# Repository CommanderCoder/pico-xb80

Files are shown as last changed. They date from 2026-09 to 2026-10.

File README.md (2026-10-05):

# pico-xb80

pico-xb80 is a small expansion-bus interface for 1970s and 1980s desktop machines, designed to allow a Raspberry Pi Pico 2 board to present an SD card-backed storage device to a Sharp MZ80K system.

https://youtu.be/xSwXQkPeJl4?si=bnu4Bi942s_XvJiR

Short Video of the pico-xb80 (http://www.youtube.com/watch?v=xSwXQkPeJl4?si=bnu4Bi942s_XvJiR "pico-xb80 on Sharp MZ80K")

## Supported hardware

Currently supported:

* [Sharp MZ80K](https://en.wikipedia.org/wiki/Sharp_MZ)

Possible future targets with additional effort:

* [Tandy TRS-80 and clones](https://en.wikipedia.org/wiki/List_of_TRS-80_clones)

## What it does

The project uses a Pico 2 board and an SD card to provide a file system to the Sharp MZ80K through the expansion bus. A small monitor ROM extension and host-side software allow the machine to access files stored on an SD card in a way that is compatible with the existing monitor and tape-handling model.

The software stack includes:

* SD card interface support for the Pico 2 board configuration used here, over hardware SPI where the wiring allows it and bit-banged 1-bit native SD mode otherwise
* `fatfs` by ChaN
* a custom expansion-bus implementation using the Pico PIO and DMA subsystems
* Sharp MZ80K-specific glue logic and ROM support for monitor commands such as `*FD`

## Hardware overview

Off-the-shelf components are used to keep the project accessible and inexpensive.

* Raspberry Pi Pico 2 / RP2350B mounted on an [Olimex Pico2-XXL](https://www.olimex.com/Products/RaspberryPi/PICO/PICO2-XXL/open-source-hardware)
* SD card socket mounted on the board
* Ribbon cable and jumper wires to connect the bus to the computer
  * Sharp MZ80K uses a [50-way ribbon cable](https://www.google.com/search?q=50+way+ribbon+cable)
  * [DuPont or similar jump wires](https://en.wikipedia.org/wiki/Jump_wire)

This is a prototype-style design intended to be simple to build and experiment with. A dedicated single-board version may be possible in the future, but the current approach uses the Olimex board for flexibility.

## Development environment

The project is built and developed with:

* VS Code
* Raspberry Pi Pico SDK
* Git - [git in VSCode](https://code.visualstudio.com/docs/sourcecontrol/overview) 
* Python 3

### Z80 code tooling

> Important: you will need to build your own copy of `sjasmplus` for your platform.

The repository includes support for:

* [sjasmplus](https://github.com/z00m128/sjasmplus) for assembling Z80 code into machine-code binaries
* `bin2header.py` to convert binary output into a C header suitable for inclusion in the Pico firmware

## Utility tools

The project includes a small set of helper scripts for working with Sharp MZ80K file images:

* `filehandle_path.py` — scans a Sharp MZ80K binary for tape-handler calls and rewrites them to use the SD-backed handlers
* `mz_tape_info.py` — inspects file images and reports the file type plus whether they have already been patched

# Build and upload

## Wiring

Only the right-hand column of pins is used from EXT1 and EXT2 on the Olimex board.

<div style="display: flex; gap: 1rem;">
  <div style="flex: 1;">

| Olimex EXT1 | MZ80K | XB Signal |
|---|---|---|
| P1 | nc | |
| P3 | A25 (mark) | D0 |
| P5 | A24 | D1 |
| P7 | A23 | D2 |
| P9 | A22 | D3 |
| P11 | A21 | D4 |
| P13 | A20  | D5 |
| P15 | A19 | D6 |
| P17 | A18 | D7 |
| P19 | nc | |
| P21 | nc | |
| P23 | nc | |
| P25 | nc | |
| P27 | nc | |
| P29 | nc | |
| P31 | B10 | NWR |
| P33 | B8 | NRD |
| P35 | B6 | NIOREQ |
| P37 | B4 | NMREQ |
| P39 | B3 | GND |

  </div>

  <div style="flex: 1;">

| Olimex EXT2 | MZ80K | Signal |
|---|---|---|
| P1 | nc | |
| P3 | A16 | A0 |
| P5 | A15 | A1 |
| P7 | A14 | A2 |
| P9 | A13 | A3 |
| P11 | A12 | A4 |
| P13 | A11 | A5 |
| P15 | A10 | A6 |
| P17 | A9 | A7 |
| P19 | nc | |
| P21 | nc | |
| P23 | A8 | A8 |
| P25 | A7 | A9 |
| P27 | A6 | A10 |
| P29 | A5 | A11 |
| P31 | A4 | A12 |
| P33 | A3 | A13 |
| P35 | A2 | A14 |
| P37 | A1 | A15 |
| P39 | nc | |

  </div>
</div>

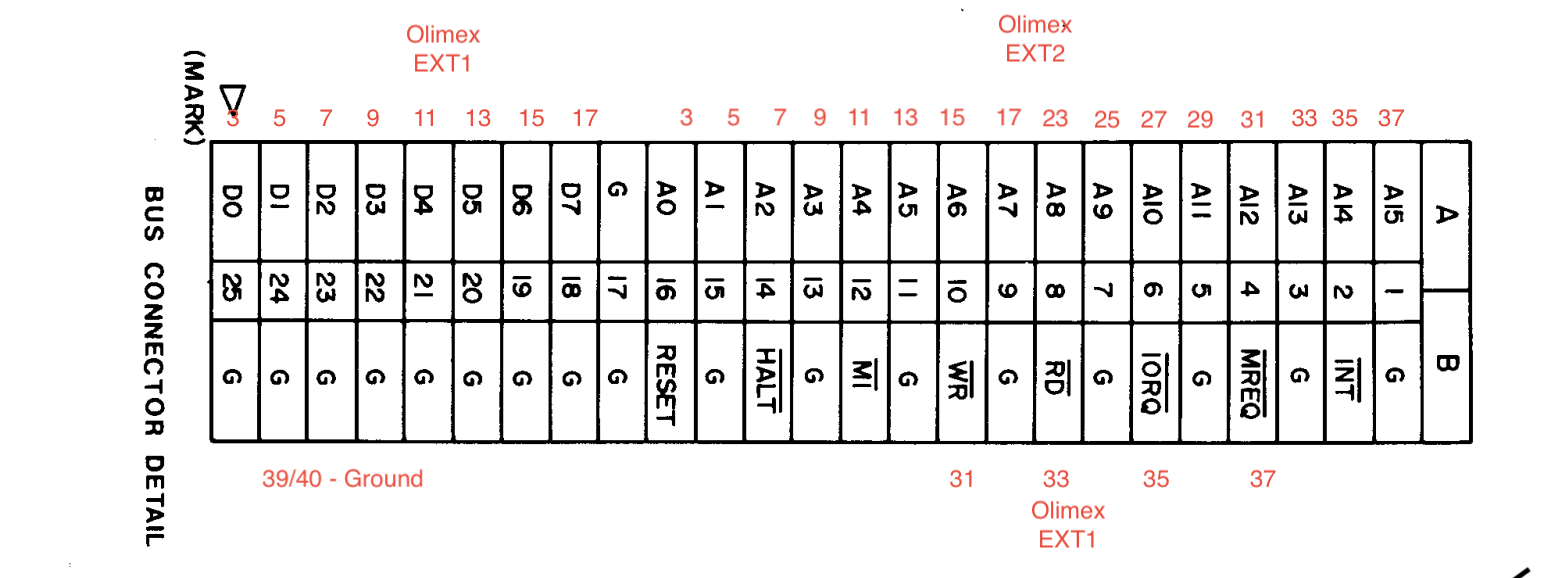
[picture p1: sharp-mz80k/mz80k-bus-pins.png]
sharp-mz80k-bus-pins


## Building

From the project root:

```bash
cmake -S . -B build -G Ninja
cmake --build build
```

## Uploading

To put the Pico into bootloader mode:

* hold the BOOT button
* connect the board to your computer via USB

Then upload the firmware using VS Code with the Pico extension, or use the project task configuration already provided in the workspace.

## SD card layout

Create an SD card with a root-level folder named `MZ_FD`. Place the files you want to access inside that directory and give them the `.MZF` extension. The file `0000.MZF` is loaded whenever `*FD` is used from the monitor.

## Patch workflow

Because the monitor ROM cannot be modified in software, a replacement ROM or a patched program image is required to redirect tape-file operations to the SD-backed handlers.

The helper scripts make this easier:

* `mz_tape_info.py` identifies files that use tape-file logic
* `filehandle_path.py` patches those files to call the SD-handler routines instead

## Power

The board can be powered either from the host laptop USB port or from a standard USB power supply.

# Operating instructions

See [OPERATING.md](OPERATING.md) for instructions on using the interface from the Sharp monitor ROM.

# Reference and acknowledgements

Thanks to:

* [MZ80K_SD](https://github.com/yanataka60/MZ80K_SD)
* [Atom-DVI](https://github.com/cmoulang/Atom-DVI)
* [MZ-80A](https://mz-80a.com/)
* [MZ-Archive](https://mz-archive.co.uk/)
* [Sharp MZ](https://www.sharpmz.net/)
* the wider retro-computing community for technical discussion and reference material

This project also benefited from discussions and examples from several AI systems used during development, but the project itself is intended to stand on its own technical merits.

# Technical notes

## The software:
* SD Card interface software (initially from prompts to Claude.ai).  The Olimex Pico2-XXL has two variants.  One use 1-bit communication protocol and the other uses the 4-bit protocol.  My board used 1-bit so the software was originally built for this.

  `SdCard::detect_board_revision()` works out which board it is running on first, since the two Olimex revisions wire the card differently.  Revision A puts SD_DAT0 on GPIO12 and leaves R24 - the link between GPIO9 and the card's CS pin - unpopulated, so it can only be bit-banged.  Revision B moved SD_DAT0 to GPIO24 (GPIO12 collides with the RP2350's HSTX/HDMI block) and ships wired for SPI.  The check is electrical, not a conversation with the card: it looks for the 10k pull-up the SD_DAT0 net carries on the board, so it needs no card in the socket and sends no commands - which matters, because a `CMD0` seen with CS low latches a card into SPI mode until it is next powered down.

  That gives two transports, picked at startup by `SdCard::initialize()`:
  * **SPI** - used on Revision B.  The card is driven by one of the RP2350 SPI blocks, so a sector moves as 512 hardware-clocked bytes at 12.5MHz rather than 4096 bit-banged GPIO transitions.  This needs CS on a GPIO and CLK/DI/DO on pins that can carry the SCK/TX/RX functions of a single SPI instance - GPIO9/10/11/24 are all `spi1`, so they qualify.
  * **1-bit native SD** - used on Revision A, and the fallback everywhere else: whenever the wiring cannot carry SPI or the card does not answer the SPI probe.  CMD/CLK/DAT0 are bit-banged at roughly 500kHz with the CPU busy-waiting for the whole sector.

  If the detected wiring fails to initialise, the other revision's wiring is tried before giving up.

* Expansion Bus - provides a shared memory on the address bus.  [Pico PIOs](https://www.raspberrypi.com/news/what-is-pio/) rapidly reads addresses and data which several DMAs pump in and out of 64Kx16bit words (128Kb).
  * heavily influenced by [ATOM-DVI](https://github.com/cmoulang/Atom-DVI) after speaking with Chris about his project at an ABUG event. 
* pico-xb80_mz80k - the specific Sharp MZ80K interface.  
  * Z80 *ROM* this is shared on the bus at `0xF000` so that the Monitor ROM can jump to it with an `*FD` command.
  * Mailbox addresses so that the Z80 can send and receive commands and data to/from the Pico
  * Communcation with the SD card via the SD Card interface and `fatfs`

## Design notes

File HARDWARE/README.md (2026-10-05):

# Hardware

## Revision 1 schematic

The [`xb80_universal.pdf`](xb80_universal.pdf) file contains the first hardware revision schamatic design for the board.

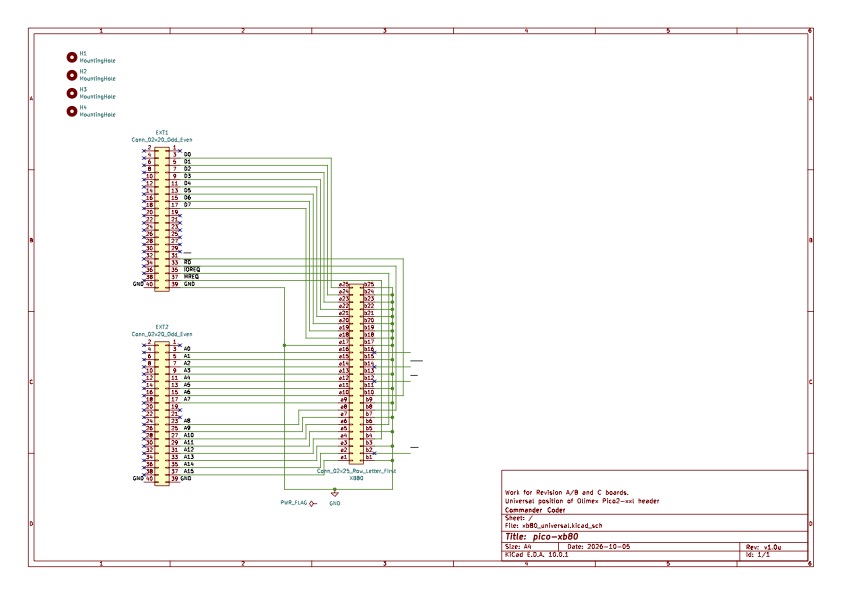
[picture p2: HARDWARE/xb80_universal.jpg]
PCB


## Revision 1 visual reference

Render of the assembled first-revision board layout and component placement for quick visual reference.

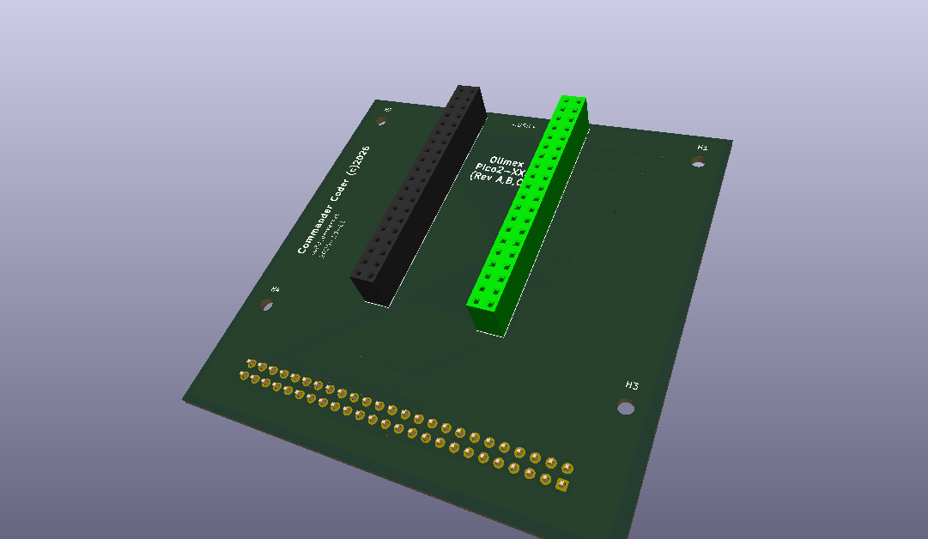
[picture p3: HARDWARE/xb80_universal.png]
SCHEMATIC


Pico on top with headers underneath.  Ribbon cable underneath that.

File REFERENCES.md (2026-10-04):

# References

 - [Olimex Pico2-XXL](https://www.olimex.com/Products/RaspberryPi/PICO/PICO2-XXL/open-source-hardware)
 - [Commented Assembly Listing for SP-5025 Monitor](https://mz-80a.com/Files/Manuals/Monitor-Disassembly-80K.pdf)
 - [Sharp MZ Manuals](https://www.sharpmz.net/mz-80k/dldsh80k.htm)
 - [MZ80K Service Manual](https://www.sharpmz.net/mz-80k/download/sm80k.pdf)
 - [Z80 CPU Manual](https://www.zilog.com/docs/z80/um0080.pdf)
 - `sjasmplus`
   - [Documentation](https://z00m128.github.io/sjasmplus/documentation.html)
   - [Installation](https://github.com/z00m128/sjasmplus/blob/master/INSTALL.md)
 - [Yanataka MZ80K-SD](https://github.com/yanataka60/MZ80K_SD)
 - [CMoulang Atom-DVI](https://github.com/cmoulang/Atom-DVI)

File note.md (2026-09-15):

I wanted to be able to load programs quickly onto my Sharp MZ80K.  Quicker than the super speedy in-built tape deck.

I hunted around and found this:
https://github.com/yanataka60/MZ80K_SD

After looking at the design I thought I might be able to use a different microprocessor
than an arduino.  An Arduino Mega maybe?  

I'd spoken with someone recently about bus sniffing with a Pico2B (RP2350B).  The 'B' model has 48 GPIO pins so that can connect to all 16 address lines, 8 data lines and 4 control lines on the MZ80K expansion bus.

So that's what I did.  I bought an Olimex Pico2-XXL https://github.com/OLIMEX/RP2350-PICO2-XXL/tree/main (it has the 48 GPIO's exposed) and it has an Micro-SD card slot.

After a couple of months of tinkering I got the Olimex to sniff read/writes on the bus so that it could intercept memory writes and reads.  This means it could respond to reads and writes between 0F000H and 0FFFFH. (I've made it possible to make individual address inactive, read-only, write-only and read-write)

The Olimex Pico2-XXL has two varients.  One with 1-bit MMC access and the other with 4-bit access.  Mine has 1 bit mmc which doesn't have that much example code.  CoPilot helped here, with some support from Claude.AI, and my own tinkering.

So now I have an SD card containing Z80 programs, SP-5025 Basic and Basic programs.  The Pico has a version of the ROM from Yanataka's site embedded into it and now I can use *FD to load binary programs, and a patched version of SP-5025 Basic to load Basic programs.

No other hardware is needed apart from ribbon cables and a USB power supply.

NOTE: The RP2350 nominally operates at 3.3v but the internet suggests it is 5v tolerant with some caveats. (A4 version of the chip is definitely tolerant but A2, which is the same as mine, requires 5V on IOVCC pin before drive the other pins.)

--

If you're interested in this, then get in touch.  I don't plan to release any code until I've tidied it up a lot.

I don't have an MZ700 so I cannot test it.

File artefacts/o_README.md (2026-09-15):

# PICO tools to upload the 

cmake -S . -B build -G Ninja

# ARDUINO-CLI tool to upload to arduino

# List all available boards
arduino-cli board listall | grep -i mega

# Detect connected boards
arduino-cli board list

cd arduino_eb_test
arduino-cli compile --fqbn arduino:avr:mega arduino_eb_test.ino

arduino-cli upload -p /dev/cu.usbserial-0001 --fqbn arduino:avr:mega arduino_eb_test.ino

# build arduino mega - mimics the Z80 cpu
ARDUINO_PORT=/dev/cu.usbserial-0001
arduino-cli compile --upload -p "$ARDUINO_PORT" --fqbn arduino:avr:mega arduino_eb_test.ino && arduino-cli monitor -c 115200 -b arduino:avr:mega -p "$ARDUINO_PORT"

# to view the output

# from pico
minicom -b 115200 -D /dev/tty.usbmodem1101

# from arduino
minicom -b 115200 -D /dev/cu.usbserial-0001

or

arduino-cli monitor -p /dev/cu.usbserial-0001 -c 115200 -b arduino:avr:mega

# build Z80

./sjasmplus test.s --lst && hexdump -v -e '8/1 "0x%02x, " "\n"' test.bin > rom1.h 

https://mz-80a.com/Files/Manuals/Monitor-Disassembly-80K.pdf

	; just show a message...
	    LD   DE, MSG_LD1
        CALL MSGPR
        CALL NEWLIN
        LD   DE, MSG_LD2
        CALL MSGPR
		CALL LETLN
        JP   MON  ; Jump back to Monitor instead of RET

CURSORHOME		EQU		16H ; clear screen

MSG_LD1: DB   CURSORHOME, 'HELLO ANDREW AND KAREN', 0DH
MSG_LD2: DB   'THIS PROGRAM IS SITTING INSIDE MY LITTLE BOX', 0DH

# MZ80K Memory Map

RAM - 48K runs from 0x1000-0xCFFF (0xC000 bytes or 49152)
Workspace RAM for Monitor - 0x1000-0x11FF
RAM for programs 0x1200-0xcfff

## Basic
0x1200-0x4806

## Monitor
0x0000-0x0fff

## Video
0xD000-0xD3FF
Only 1000 locations seen. The other 24 are never shown
The locations are repeated 4 times, so making the 4096 addresses up to DFFF

MZ80A has 2k of video ram but each 1k selected in a special way.

## Memory Expansion & Addressing

## I/O At $E000 Locations

E000 keyboard driver
E001 keyboard receiver
E002 read-curser timer, cassette sense
E003 motor pulse, led

*8522 PIA*
E000 BEING PORT A
E001 BEING PORT B
E002 BEING PORT C
E003 BEING THE CONTROL WORD

all the peripherals ; 

*8253 TIMER*
E007 CONTROL WORD.
E006 COUNTER 2
E005 COUNTER 1
E004 COUNTER 0

*555 TEMPO TIMER*
E008 timer

### MZ80A EXTRAS
E00C MEMORY MONITOR EXCHANGE
E010  MEMORY MONITOR NORMAL
E014 STADNARD SCREEN DISPLAY
E015 REVERSE SCREEN DISPLAY
E200-E2FF DISPLAY RAM

_Maybe use 0xE300 for moving data to and from the PICO, But F000-FFFF is reserved and available_

MZ80A - has user ram/rom slot addressed at E800-EFFF - if E800 is NULL then this rom will run on powerup
..
plenty more

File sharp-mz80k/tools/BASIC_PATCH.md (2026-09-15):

# PATCHING BASIC

Load and Save routines exist within the MONITOR rom.  Cannot patch the Monitor ROM (hardware) using software
so any program which loads or saves will need to be patched.  

This can be done by searching through the machine code looking for jumps to the load or save routines.

These routines are in the monitor ROM at these location, and have these hex codes to jump.
 ADDR MC     LABEL: pseudo-assembler
 0021 C33604 PHEAD: JP Phead Punch header.
 0024 C37504 PDATA: JP Pdata Punch data.
 0027 C3D804 LHEAD: JP Lhead Load header.
 002A C3F804 LDATA: JP Ldat a Load data.
 OO2D C38805 CHECK: JP Check Checks file.

0xC3 is the JP instruction, and PHEAD code is at location 0x0436 in the monitor rom, for example.

Normal Sharp assembler programs will jump to 0x0021 (for example) and this will jump to 0x0436 which performs the 'write' header. (Punch was used for Write back in the 1970's on this machine).

## Without changing the rom

The replacement jump functions are in the FD rom at these locations:

 F004 C3 E7 F7     ENT1: 	JP		MSHED ; PHEAD (punch header)
 F007 C3 32 F8     ENT2: 	JP		MSDAT ; PDATA (punch data)
 F00A C3 66 F8     ENT3: 	JP		MLHED ; LHEAD (load header)
 F00D C3 50 F9     ENT4: 	JP		MLDAT ; LDATA (load data)
 F010 C3 83 F9     ENT5: 	JP		MVRFY ; CHECK (Checks file)

Need to patch every program. The first of these is naturally BASIC.  To patch BASIC need to look for 

 CALL 0021H
 and replace with
 CALL F004H

 CALL 0027H
 and replace with
 CALL F00AH

 so simply search through the BASIC binary and replace
 0xcd, 0x21, 0x00 _with_ 0xcd, 0x04, 0xf0
 0xcd, 0x24, 0x00 _with_ 0xcd, 0x07, 0xf0
 0xcd, 0x27, 0x00 _with_ 0xcd, 0x0a, 0xf0
 0xcd, 0x2A, 0x00 _with_ 0xcd, 0x0d, 0xf0
 0xcd, 0x2D, 0x00 _with_ 0xcd, 0x10, 0xf0

# Monitor ROM patch for FD_rom1.s

If you feel patching the ROM would be best, thus works for ALL existing Sharp programs then 
you replace the code at these locations to jump to the routines in the FD rom.

　0437 : D5 → C3
　0438 : C5 → 04
　0439 : E5 → F0
== JP F004

　0476 : D5 → C3
　0477 : C5 → 07
　0478 : E5 → F0
== JP F007

　04D9 : D5 → C3
　04DA : C5 → 0A
　04DB : E5 → F0
== JP F00A

　04F9 : D5 → C3
　04FA : C5 → 0D
　04FB : E5 → F0
== JP F00D

　0589 : D5 → C3
　058A : C5 → 10
　058B : E5 → F0
== JP F010

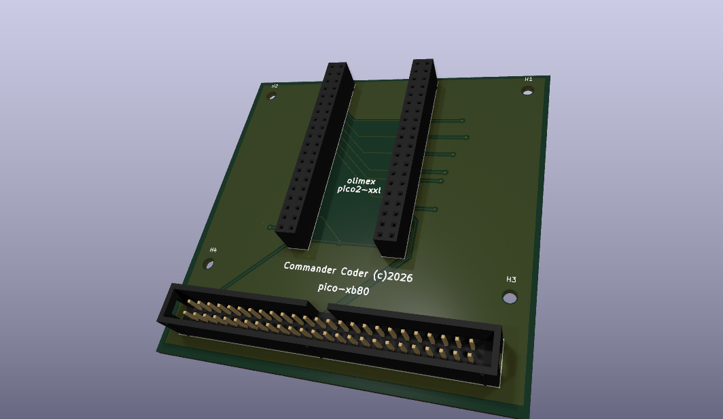
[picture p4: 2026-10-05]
HARDWARE/xb80_1/xb80_1.png

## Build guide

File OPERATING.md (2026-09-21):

# Operator Guide

## Preparing SD Card

All files must be within a subfolder called /MZ_FD and they must be binary files (no zips *yet*) and they must have the extension `.mzf` (case insensitive)

## `*FD`

Boot the file named 0000.mzf on the SD card use.  This is a convenience to startup any application quickly on the machine. A copy of BASIC is usually a good choice for this file.

## `*FDF`

Boot a File Menu which lists all files on the SD card.

# File Menu

## Help

> H

Display a help page explaining these navigation keys using 1 or 2 word phrases.

## Navigation

> W S

Use W/S to move up and down the list.

> , .

Use `,` and `.` to turn pages backward and forward (if there are multiple pages of files).

> X or ENTER

Load and execute (run) the file

> L

Load the file but do not execute it.  The load address is reported and you are returned to the monitor, so the loaded program can be started with `G` when you are ready.

> F

Filter the list by the next letter that you type. e.g. `F  B` would list only files beginning with B.

Press ENTER or SHIFT+BREAK at the `FILTER LETTER?` prompt to clear the filter and show every file again.

> T

Toggle between showing Basic, Machine code and other file types.  Each press cycles `ALL` → `BASIC` → `M-CODE` → `OTHER` → `ALL`, and the current setting is shown on the status line at the top of the screen.

A file counts as machine code when its MZF header type byte is 01H, as Basic when it is 02H, and as other for any other value.

> A

Copy the file to `0000.mzf`.  This enables changing the autoboot file from within the file menu.

> C 

Copy this file.  You will be prompted for a new filename.  If the new filename is the same as another [IBF filename](#ibf-filename) then the operation will fail.

The new name is applied to both the [IBF filename](#ibf-filename) and the SDCard filename of the copy, so the copy does not inherit the original's name.

> R

Rename this file.  You will be prompted for a new filename.  If the new filename is the same as another [IBF filename](#ibf-filename) then the operation will fail.

The new name is applied to both the [IBF filename](#ibf-filename) and the SDCard filename, exactly as it is when saving.  This is the way to give a file a name of its own when it shares one with another file.

> D

Delete this file. You will be prompted to confirm.

> P

Printout (Dump to screen) the contents of the file as 128 bytes per screen.

Once one screen is displayed, it will show "NEXT:ANY BACK:B BREAK:SHIFT+BREAK" and wait for instructions. Press B to display the previous 128 bytes, SHIFT+BREAK to cancel, and any other key to display the next 128 bytes.

If the file size is not divisible by 128 bytes, the last page will be filled with 00H until it reaches 128 bytes.

> SHIFT+BREAK

Exit back to the monitor.

## Filenames

Filenames on cassette are limited to 16 characters (plus a terminator character).

Filenames on the SD card have a much larger limit, but when listing filenames and referencing files from programs like BASIC, the [IBF filename](#ibf-filename) is used from with in the file header.

### IBF filename

Because files on tape or punch cards came sequentially, the filename is stored within the header of the file and not in a file table like they are on hard drives.  This filename is called the IBF by Yanataka.

The File Menu lists IBF filenames, and every command that takes a filename matches on the IBF filename first, falling back to the SDCard filename if nothing matches.  That fallback is what lets `*FD` find `0000.mzf`, whose IBF filename is whatever program it happens to hold.

### Duplicate IBF filenames

Nothing stops two files having the same IBF filename, and it happens easily: a patched copy of a program usually keeps the header of the original it was made from.

Where several files share an IBF filename, the listing tags each one `<1`, `<2`, `<3` and so on, in the order they are found on the card:

```
BASIC SP-5025<1
BASIC SP-5025<2
```

The tag is added to the end of the name, or replaces the last few characters when the name is already too long to grow.

In the File Menu the tags are only there so you can tell the rows apart: every operation (`X`, `L`, `A`, `C`, `R`, `D`, `P`) acts on the highlighted row itself, never on its name, so it always affects exactly the file you are pointing at.

> The tags exist only in the listing.  **The files on the card are not altered** and their headers still hold the original name, so a tag can move if you add or remove files.  Use `R` to give a file a name of its own if you want one that will not change.

Where a file must be named — from BASIC or the command line — the tagged name picks out one particular file, and an untagged name finds the first file carrying it.

## Loading from BASIC and other programs patched for `Pico-XB80`

BASIC and other programs will call routines within the monitor to load and save (*punch*) files.  These would take the file in memory and save it to cassette (or punch card!) starting at a known address, for a known length, and with a known execution address when it is loaded again.

> ⚠️ SAVE filenames must have fewer than 17 characters.

Just like with Cassette (CMT), please enter the file name and other information according to the input method and rules specified by the application and save it.

When saving, the entered filename will be applied to both the [IBF filename](#ibf-filename) and the SDCard filename.

The `.mzf` extension is automatically added to the SDCard filename.

For example, in BASIC SP-5030...

`SAVE "TEST"`

Will create a BASIC file called TEST.mzf with the IBF filename `TEST`.

> ⚠️ LOAD filenames must have fewer than 17 characters.

Although you can specify an IBF file name after commands such as L and LOAD specified by the application, simply press the ENTER key after the command such as L or LOAD without specifying an IBF filename will display the File Menu.

# Additional Command Line (after Yanataka MZ80K-SD)

## FD

The following commands are available from the MONITOR command input.  That is the `*` prompt.  All filenames are their [IBF filename](#ibf-filename) not the filename on the SDCard.

> FDS saddr eaddr xaddr filename

This command saves the data from the save start address to the save end address using the given filename.  The filename must have fewer than 17 characters and it will be the IBF filename, and the SDCard filename suffixed with `.mzf`

The save start address, save end address, and execution start address are specified using 4-digit hexadecimal numbers.

`*FDS　1200　2FFF　1200　TEST`

> FDM saddr

This displays the memory contents of the MZ-80K, starting from the address, in 128-byte segments per screen.

Once one screen is displayed, it will show "NEXT:ANY BACK:B BREAK:SHIFT+BREAK" and wait for instructions. Press B to display the previous 128 bytes, SHIFT+BREAK to cancel, and any other key to display the next 128 bytes.

You can cancel the display at any time by pressing SHIFT+BREAK, even while a single screen is being displayed.

> FDW saddr hexbytes* [CR]

The hexbyte (multiple 2-digit hexadecimal values), starting from the address, is written to the MZ-80K's memory.

Enter the data to be written as two hexadecimal digits after the starting address, and then press the ENTER key. Spaces separating the data will be ignored, so they can be included or omitted.

You can have any number of byte data entries in a 2-digit hexadecimal format, as long as they fit on a single line.

Enter a line of data and press the ENTER key to write it into memory. The next address will then be displayed, allowing you to continue entering data.

Furthermore, by correcting the address, it is possible to go back and make corrections or write data to a different address.

To stop writing data, press the ENTER key without writing any data to the displayed address.

If you enter a number other than hexadecimal and press the ENTER key, the system will write the valid data up to the point immediately before the non-hexadecimal input and display the next address.

`*FDW　1200　01　02　03　04　05　06　07　08`

`*FDW　1200　0102030405060708`

`*FDW 1200` (when stopping)

`*FDW 1200 12 34 5/` (Written up to 12 34)

# MZ700

    There is no support for MZ700 yet.

Note that while the MZ-700's floppy disk drive startup command is actually just the letter 'F', we've standardized the operation method to use 'FD'.

FDZ[CR]
　[For MZ-700 only] This program functions the same as "FT.MZT," which was created for the MZ-700. After copying MONITOR 1Z-009A or 1Z-009B to the back RAM and applying the patch, the MONITOR on the back RAM will start.

　If executed on an MZ-80K, it will result in a RESET operation.

FDU[CR]
　[For MZ-700 only, only when resetting while operating with the rear RAM MONITOR] Switches to rear RAM and starts the rear RAM MONITOR.

　Note: Running this program without the MONITOR module in the background RAM will cause it to malfunction.

　If executed on an MZ-80K, it will result in a RESET operation.

# S-OS SWORD

    This is untested.

When using [S-OS SWORD](https://handwiki.org/wiki/Software%3AS-OS), immediately after startup, set the device to "DV S:" and configure each device as a SYSTEM device.

This might only be the case with FUZZY BASIC, but when using a common format device, I couldn't omit the IBF file name with the LOAD command.

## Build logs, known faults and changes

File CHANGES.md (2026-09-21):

# Changes

Bringing `sharp-mz80k/FD_rom.s` into line with `OPERATING.md`.

`OPERATING.md` was treated as the specification throughout. Where the ROM and the
document disagreed, the ROM was changed; the document was only edited where it
contradicted itself or left behaviour undefined.

## Summary

Before this pass the ROM implemented roughly a quarter of what the operator guide
described. There was no monitor command-line parser at all — `*FD` went straight to
the file menu — and the menu supported six keys out of the thirteen documented. Four
of the Pico-side handlers that the documented menu operations depend on were
addressing the wrong directory and could never have succeeded.

Every monitor command and menu key documented in `OPERATING.md` is now implemented. The
ROM grew from 1342 to 3181 bytes, leaving 908 bytes of the 4089-byte budget free.

One documented behaviour is still missing: the guide says that pressing ENTER after
`LOAD` without naming a file should bring up the File Menu. `MLHED` still reports
`NO FILENAME` instead. Entering the menu from inside BASIC means never returning to it,
so this needs a decision about what should happen afterwards rather than a quick patch.

---

## Decision that needed a call

`OPERATING.md` assigned `A` and `D` to two different things each: page-back and
page-forward under "Navigation", and "copy to 0000.mzf" (`A`) and "delete" (`D`) in
the per-key list below it. Both could not be true.

Resolved in favour of the per-key list, because it is the more detailed and more
recently written of the two. Paging moved to `,` and `.`, and the Navigation section
of `OPERATING.md` was updated to match.

---

## `sharp-mz80k/FD_rom.s`

### Monitor command line — all of this was missing

The ROM had no parser. It jumped straight to the file menu from `0xF001`, so none of
the documented commands worked and `*FD` did the wrong thing.

Added `FDSTART`, which reads the command line out of `LBUF` (tolerating a missing
`*` prompt character) and dispatches:

| Command | Behaviour |
| --- | --- |
| `*FD` | Loads and runs `0000.mzf` (SD command `0x81`) |
| `*FDF` | Opens the file menu |
| `*FDS saddr eaddr xaddr name` | Saves a memory block (SD command `0x80`) |
| `*FDM saddr` | Displays memory, 128 bytes per screen — no Pico traffic |
| `*FDW saddr hexbytes` | Writes hex byte pairs into memory, then re-prompts |

`*FDS` validates that the end address is above the start address and that a filename
is present, reporting `ADDRESS FAILED!` / `FILENAME FAILED!` as the guide describes.

`*FDM` honours the documented "cancel at any time with SHIFT+BREAK, even while a
single screen is being displayed" by testing the key between every byte printed, not
just at the page prompt.

`*FDW` re-prints `*FDW nnnn ` after each line so the monitor's line editor picks the
whole line back up, stops on an empty line, and writes the valid data up to the first
non-hex character — all as documented.

### File menu keys

Previously only `W`, `S`, `A`, `D`, `R`, `/` and BREAK did anything. Now:

| Key | Action | Status |
| --- | --- | --- |
| `W` / `S` | Up / down one line | was present |
| `,` / `.` | Page back / forward | replaces `A`/`D` |
| `X` or ENTER | Load and run | `X` added |
| `L` | Load without running | added |
| `H` | Help page | added |
| `F` | Filter by next letter typed | replaces the old `/` line-input search |
| `T` | Cycle ALL → BASIC → M-CODE → OTHER | added |
| `A` | Copy to `0000.mzf` (SD `0x82`) | added |
| `C` | Copy file (SD `0x87`) | added |
| `R` | Rename file (SD `0x85`) | added, was "run" |
| `D` | Delete file (SD `0x84`) | added, was "next page" |
| `P` | Print/dump file (SD `0x86`) | added |
| SHIFT+BREAK | Exit to monitor | was present |

`L` reports the load address and returns to the monitor rather than to the menu,
since a loaded program may sit on top of the menu's own work area at `0xC800`.

A status line now shows the active type filter and letter filter.

### Key code handling — corrected

The monitor's `GETKY` at `001BH` returns *device* codes, not plain ASCII: CR is `66H`
and SHIFT+BREAK is `64H` (confirmed against the SP-1002 subprogram documentation).
Both alias onto lower-case letters once bit 5 is cleared — `64H & 5FH` is `'D'` and
`66H & 5FH` is `'F'`.

The older `artefacts/FD_rom_v0.1.s` masks with `AND 5FH` *before* testing for BREAK,
which means BREAK reads as `D` and CR reads as `F`. That idiom was deliberately **not**
carried over. The new dispatcher tests `64H` and `66H` first and never masks, which is
what makes it safe to bind `D` (delete) and `F` (filter) at all.

### Paging with a filter active — fixed

`GET_PAGE` used to start at raw index `page × 16` and scan exactly 16 entries, keeping
whichever matched. With a filter on, that produced short pages and silently skipped
files. It now counts *matching* entries: it skips `page × 16` matches, then collects up
to 16 more.

### Repeated directory rescans — fixed

`LOAD_SELECTED` called `GET_FILE_COUNT` on every iteration of its file-scanning loop,
and each of those triggers a full directory scan on the Pico. The scan is gone
entirely: `GET_PAGE` now records each row's Pico file index in a new `INDEX_BUFFER`,
so the selected file is looked up directly.

### Other fixes in the ROM

- `CLEAR_SCREEN` used to reset `CURSOR_POS`, so every redraw jerked the highlight back
  to the top of the page. It now only clears the screen.
- `DRAW_SCREEN` clamps `CURSOR_POS` to the last populated row, so changing a filter
  cannot leave the marker pointing past the end of a now-shorter page.
- `MOVE_DOWN` returned the cursor unchanged on an empty page and could step past the
  end if `CURSOR_POS` was already out of range; both are now guarded.
- Filenames are sent with the new `SNDNAME`, which emits the name, its CR, then NUL
  padding to exactly 33 bytes. The Pico needs the CR for `addmzf()` and the NUL for
  `addrootdir()`; the old code sent whatever happened to follow the name in memory.
- `*FDW`'s re-prompt loop now detects a BREAK out of `GETL` (reported as `1BH` in the
  first column) instead of re-parsing a line that is not there and looping forever.
- Dropped the unused `STCMD` wrapper and the write-only `FILE_COUNT` variable.
- `ENT1`–`ENT5` remain at `0xF004`, `0xF007`, `0xF00A`, `0xF00D` and `0xF010` —
  verified against the addresses `sharp-mz80k/tools/filehandle_patch.py` patches in.

---

## `sharp-mz80k/sharp_mz.cpp`

### Wrong directory on four handlers — fixed

`f_del()`, `f_ren()`, `f_dump()` and `f_copy()` called `addmzf()` but never
`addrootdir()`, unlike `f_save()`, `astart()` and `mon_whead()` which call both.

`ffconf.h` sets `FF_FS_RPATH 2` and nothing in the project ever calls `f_chdir()`, so a
bare `TEST.mzf` resolves to `/TEST.mzf` — not `/MZ_FD/TEST.mzf`. Every delete, rename,
dump and copy would therefore have reported "file not found". Since `OPERATING.md`
documents all four as working menu operations, they had to be fixed for the new ROM
keys to do anything.

Added a `recv_path()` helper that receives the name and builds the full path. It also
guarantees the CR and NUL terminators that `addmzf()` and `addrootdir()` each rely on,
which the raw 33-byte read did not.

### `FILEINFO` (`0xA1`) now reports the file type

The `T` key needs to know whether each file is BASIC or machine code, and the listing
protocol carried only the name. `sendFileName()` now sends the MZF header type byte
(header offset 0) immediately after the status byte and before the name.

`getFileAttribute()` reads that byte by opening the file at the given index. It is read
per listed entry rather than cached during `establishFileList()`, which would have
added an open for all 255 possible files to every directory scan.

**This is a protocol change.** The ROM and the Pico firmware must be updated together —
an old ROM against this firmware will read the type byte as the first character of the
filename.

### Off-by-one in ROM upload

`SharpMZ_initialise()` copied the ROM with `i <= fd_rom_start + fd_rom_size`, reading
one byte past the end of `fd_rom_data[]`. Changed to `<`.

---

## `OPERATING.md`

Only the parts that were self-contradictory or undefined:

- Navigation split into `W`/`S` for line movement and `,`/`.` for paging, resolving the
  clash with `A` (autoboot copy) and `D` (delete).
- `R` and `C` now state that the new name is written to the IBF filename as well as
  the SDCard filename. The guide said this for SAVE but not for rename or copy, which
  left it ambiguous whether a rename touches the header.
- `L` now states that it reports the load address and returns to the monitor.
- `F` now states that ENTER or SHIFT+BREAK at the prompt clears the filter. The guide
  described how to set a filter but not how to remove one.
- `T` now states that it cycles through three settings rather than two. A two-way
  toggle gives no way back to showing every file, which contradicts `*FDF` listing all
  files on entry. Also records that type byte `01H` means machine code.

The `H` (help) entry was already present and is unchanged.

---

## IBF filenames used for listing and matching

`OPERATING.md` is explicit that the name a user sees and types is the **IBF name** —
the one stored inside the file header — not the name on the SD card:

> "when listing filenames and referencing files from programs like BASIC, the IBF
> filename is used from within the file header"
>
> "All filenames are their IBF filename not the filename on the SDCard."

The code used the SD card filename throughout. That is now fixed.

### Reading the name out of the header

`FileEntry` gained `displayname` (the IBF name) and `attr`, both filled by a new
`readHeaderInfo()` that reads the first 18 bytes of each file: byte 0 is the type and
bytes `01H`–`11H` are the name, CR-terminated. Space padding is trimmed from both ends
— a leading space would otherwise defeat the menu's first-letter filter.

A file with no readable header falls back to its SD filename minus `.mzf`, so a damaged
file is still listed and still reachable rather than showing as a blank row.

This also replaced the per-entry `getFileAttribute()` open added earlier: the type byte
now comes from the same read as the name, so listing costs one file open per entry
instead of two.

### Matching a name back to a file

New `resolve_name()` maps a name from the Z80 to a real SD path, trying in order:

1. exact IBF name
2. exact SD filename
3. IBF name prefix (only for BASIC's `LOAD`, which allows abbreviation)

Step 2 is what keeps `*FD` booting `0000.mzf` by its SD name — that file's IBF name is
whatever program it holds, so an IBF-only lookup would break the documented autoboot.

Now resolving through IBF names: `f_del`, `f_ren`, `f_dump`, `f_copy`, `astart`,
`f_load` and `mon_lhead`. `sendFileData` still uses the SD path directly because the
menu loads by index, not by name.

`dirlist` (`0x83`) was rewritten to walk the cached list and send IBF names, which also
fixed its "previous page" branch — it reopened the directory and reset to page 1, so
paging back always jumped to the start.

#### `LOAD "CURS"` looped on the header step — fixed

Step 3 found the right file, but BASIC does its own check after `LHEAD` returns: at
`2A83H` it compares the name in the header buffer (`10F1H`) byte-for-byte with the name
typed, and on any difference jumps back to `CALL F00AH` — the tape "skip to the next
file" loop. With `CURSED CHAMBERS` in the header and `CURS` requested, the `E` where
BASIC expects the CR terminator failed the compare every time, so the header was
fetched again forever. The full name worked because the compare passed.

`mon_lhead` now writes the requested name into bytes 1–17 of the header it returns
(CR padded, as saved headers are) whenever a name was given. This also covers a match
by SD filename and a `NAME<n` tag, both of which differ from the header name in the
same way. The file on the card is untouched; a monitor `L` with no name gets the
header as stored.

### Rename and copy update the header

Since the listing shows IBF names, renaming or copying a file now writes the new name
into the header as well (`write_ibf_name()`). Without that, a rename would appear to do
nothing in the menu.

Both check the destination against existing **IBF** names, as the guide describes.
Rename excludes the file being renamed from that check, so giving a file an IBF name
that already matches its own SD filename is not reported as a collision with itself.

### Duplicate IBF names are tagged in the listing

IBF names are not unique, and duplicates are common in practice — a patched `_FD` build
keeps the same header name as the original it came from. Three of the seven distinct
IBF names in `sharp-mz80k/mzFiles/` are duplicated for exactly this reason.

Left alone that is dangerous: the second file of a pair is unreachable by name, so a
menu delete or rename aimed at it would silently act on the first instead.

`disambiguateNames()` now tags each member of a duplicate group `<1`, `<2`, `<3` … in
directory-scan order, so every file can be named on its own. The tag is appended, or
overwrites the tail when the name is already too long to grow:

| SD filename | listed as |
| --- | --- |
| `BASIC_SP_5025.mzf` | `BASIC SP-5025<1` |
| `BASIC_SP_5025_FD.mzf` | `BASIC SP-5025<2` |
| `EXTENDED-SP5025-BASIC-80K-FD.mzf` | `*EXTENDED BASIC<1` |
| `EXTENDED-SP5025-BASIC-80K.mzf` | `*EXTENDED BASIC<2` |

**Only the scanned listing is tagged — no file on the card is modified.** `FileEntry`
keeps both forms: `rawname` is exactly what the header says, `displayname` carries the
tag. They are used differently:

- `resolve_name()` matches the tagged name first (the only way to single out one file
  of a group), then the raw header name, then the SD filename, then a raw-name prefix.
  So `LOAD "BASIC SP-5025"` from BASIC still works untagged and finds the first match.
- `ibf_name_taken()` compares against `rawname`, because a tag is a label this scan
  invented and must not make a name look free or taken when rename and copy check it.

Because a tag depends on what else is on the card, it can move when files are added or
removed. `OPERATING.md` says so and points at `R` for giving a file a permanent name of
its own.

### Menu file operations act by index, not by name

Even with tags, sending a *name* back to the Pico for delete, rename, copy, print and
autoboot left a window where the Pico's rescan could number the duplicates differently
from the listing the user was looking at. The ROM already records each row's Pico file
index in `INDEX_BUFFER` for loading, so those five operations now send that index too.

Five index-based commands were added alongside the existing `0xA0`–`0xA2` family:

| Command | Code | Replaces |
| --- | --- | --- |
| `FILEDEL_IDX` | `0xA3` | `FILEDEL` `0x84` |
| `FILEREN_IDX` | `0xA4` | `FILEREN` `0x85` |
| `FILEDUMP_IDX` | `0xA5` | `FILEDUMP` `0x86` |
| `FILECOPY_IDX` | `0xA6` | `FILECOPY` `0x87` |
| `ASTART_IDX` | `0xA7` | `ASTART` `0x82` |

Each has the same shape as `FILELOAD`: command, dispatch ack, index byte, status — and
from the status onward the exchange is byte-for-byte identical to the name-based
version. On the Pico each operation was split into a `*_core(path)` that does the work
and two thin wrappers that only differ in how they find the path (`resolve_name()` for
the name-based command, `recv_source_index()` for the index-based one). The name-based
commands still exist, unchanged in behaviour, for anything that must address a file by
name.

In the ROM, `GET_SELECTED` (which re-fetched the row's name from the Pico) became
`SEL_INDEX`, and a shared `SEND_INDEX_CMD` sends command + index and returns the
status. Rename and copy still prompt for the new name *before* opening the exchange, so
a cancelled prompt cannot leave the Pico waiting mid-protocol. The ROM shrank by 62
bytes as a result of no longer shipping names back.

`OPERATING.md` now says that menu operations act on the highlighted row, and that tags
matter only for telling rows apart there — naming a file is only needed from BASIC or
the command line.

### ROM name field widened

The cached name field grew from 16 bytes (15 characters) to `NAME_FIELD` = 18 bytes
(17 characters plus CR), so a full-length IBF name and its tag both stay visible —
`*EXTENDED BASIC<1` is 17 characters and would otherwise have been cut back to
`*EXTENDED BASI`, hiding the very tag that distinguishes it.

`PAGE_BUFFER` therefore grew from 256 to 288 bytes and the buffers after it moved:
`ATTR_BUFFER` to `0C950H`, `INDEX_BUFFER` to `0C960H`, `NAMEBUF` to `0C970H`. The slot
address calculation in `STORE_ENTRY` is now `slot * 18` rather than a shift by four.

## Pre-existing bug found: `f_save` wrote a malformed header

`f_save()` wrote the type byte, the 17-byte name, and then **an extra null** before the
size, load and exec addresses. That pushed all three fields one byte past where the MZF
format puts them (`12H`, `14H`, `16H`) and one byte past where `f_send()` reads them
back, so anything saved with `*FDS` would have reloaded with the wrong size and
addresses.

The stray null is gone and the trailing pad grew from 103 to 104 bytes to keep the
header at 128. `mon_whead()` was never affected — it writes the 128-byte header
verbatim from the Z80.

## Verification

- `sjasmplus` assembles clean: 0 errors, 0 warnings.
- Full Pico firmware links clean via `ninja`.
- ROM is 3181 bytes against the 4089-byte limit asserted in `SharpMZ_initialise()`.
- Entry point addresses checked byte-for-byte in the generated `FD_rom.h` against
  `filehandle_patch.py`.
- Every ROM/Pico exchange was traced by hand against the handler in `sharp_mz.cpp` —
  byte counts and status-byte ordering for save, load, astart, delete, rename, copy,
  dump, file count and file info.
- The header-parsing logic was run against the real `.mzf` files in
  `sharp-mz80k/mzFiles/`, and returns sensible IBF names and type bytes for all ten.
- The duplicate-tagging pass was run over the same ten files: all ten listed names come
  out unique, and the longest is 17 characters — exactly what the widened field holds.

**Not tested on hardware.** No MZ-80K was available, so nothing here has been run on a
real machine. The command-line commands (`*FDS`, `*FDM`, `*FDW`) and the new menu file
operations are the least proven: they depend on monitor routines (`HLHEX`, `TWOHEX`,
`PRTWRD`, `ADCN`, `DISPCH`) whose register-preservation behaviour was inferred from the
working code in `artefacts/FD_rom_v0.1.s` rather than from a datasheet. The call
patterns used here mirror that file's.

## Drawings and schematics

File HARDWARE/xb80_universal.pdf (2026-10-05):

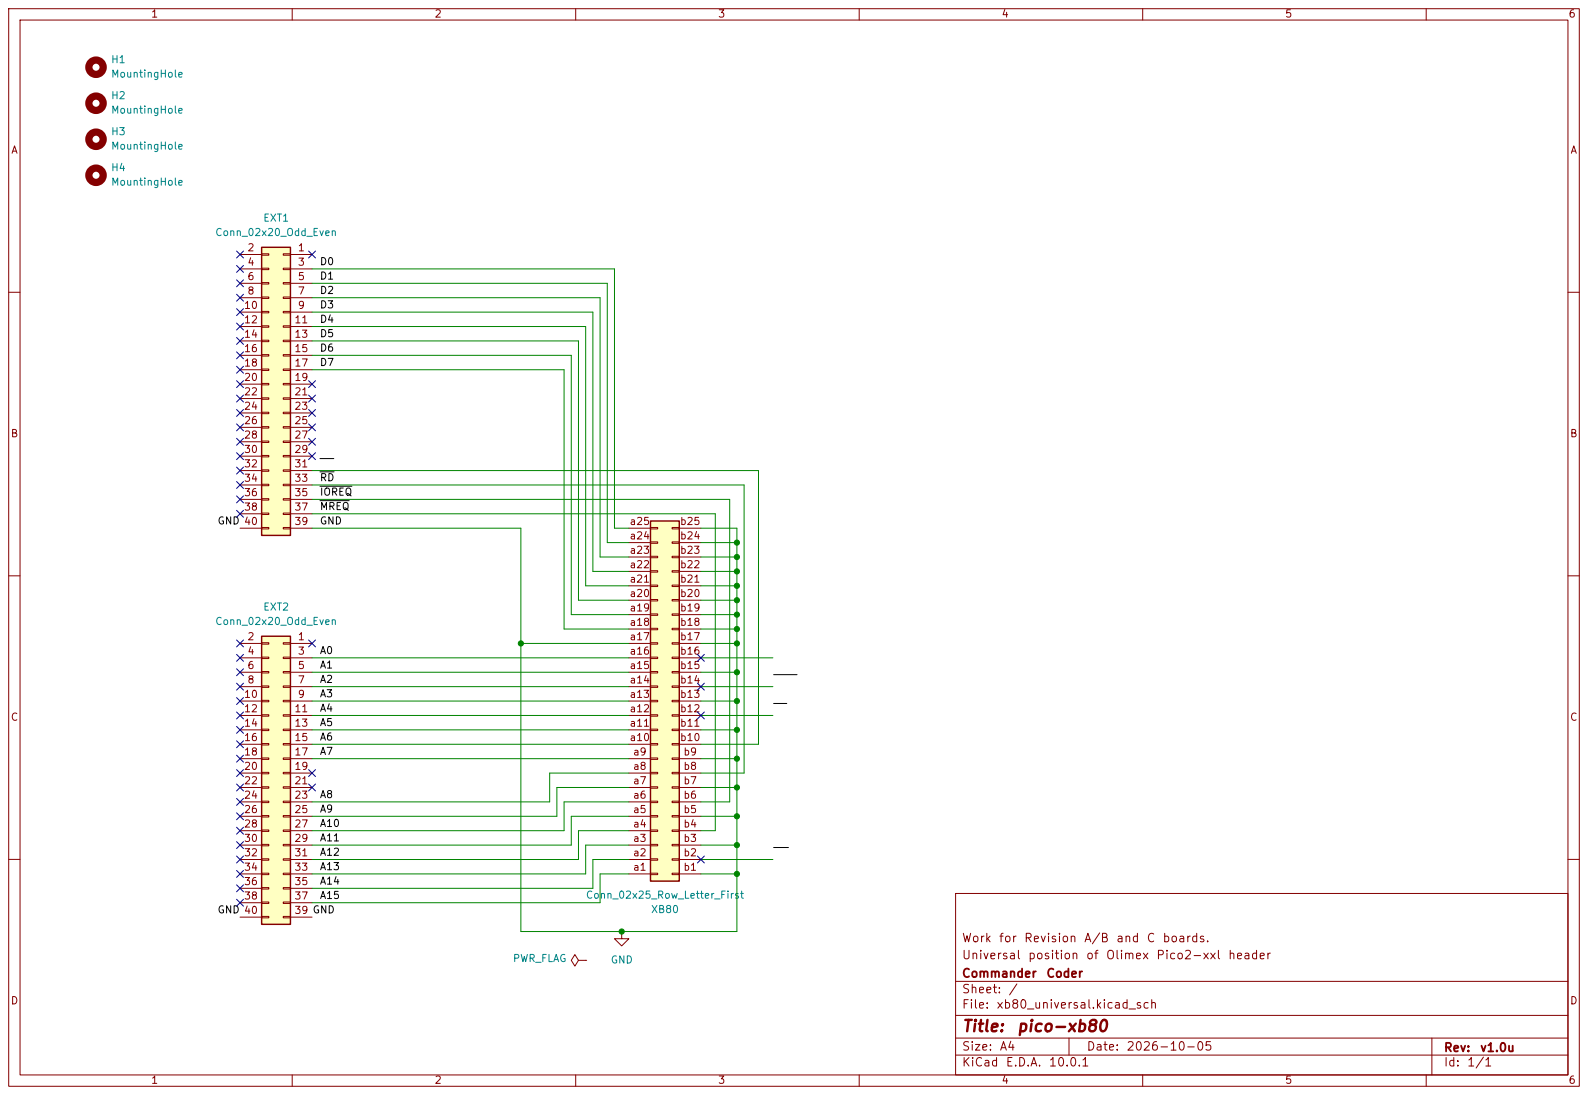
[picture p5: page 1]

RD
IOREQ

a14 | | b14 b13
a13

A7 | a9 | | b9
A8 | a8 | | b8

a7 | | b7
a6 | | b6
a5 | | b5

A10 | | a4 | | b4
A11 | | a3 | | b3
A12 | | a2 | | b2 b1
A13 | | a1

Universal position of Olimex Pico2-xxl header
Commander Coder
Sheet: /
File: xb80_universal.kicad_sch
Title: pico-xb80

Size: A4 | Rev: v1.0u
KiCad E.D.A. 10.0.1 | Id: 1/1

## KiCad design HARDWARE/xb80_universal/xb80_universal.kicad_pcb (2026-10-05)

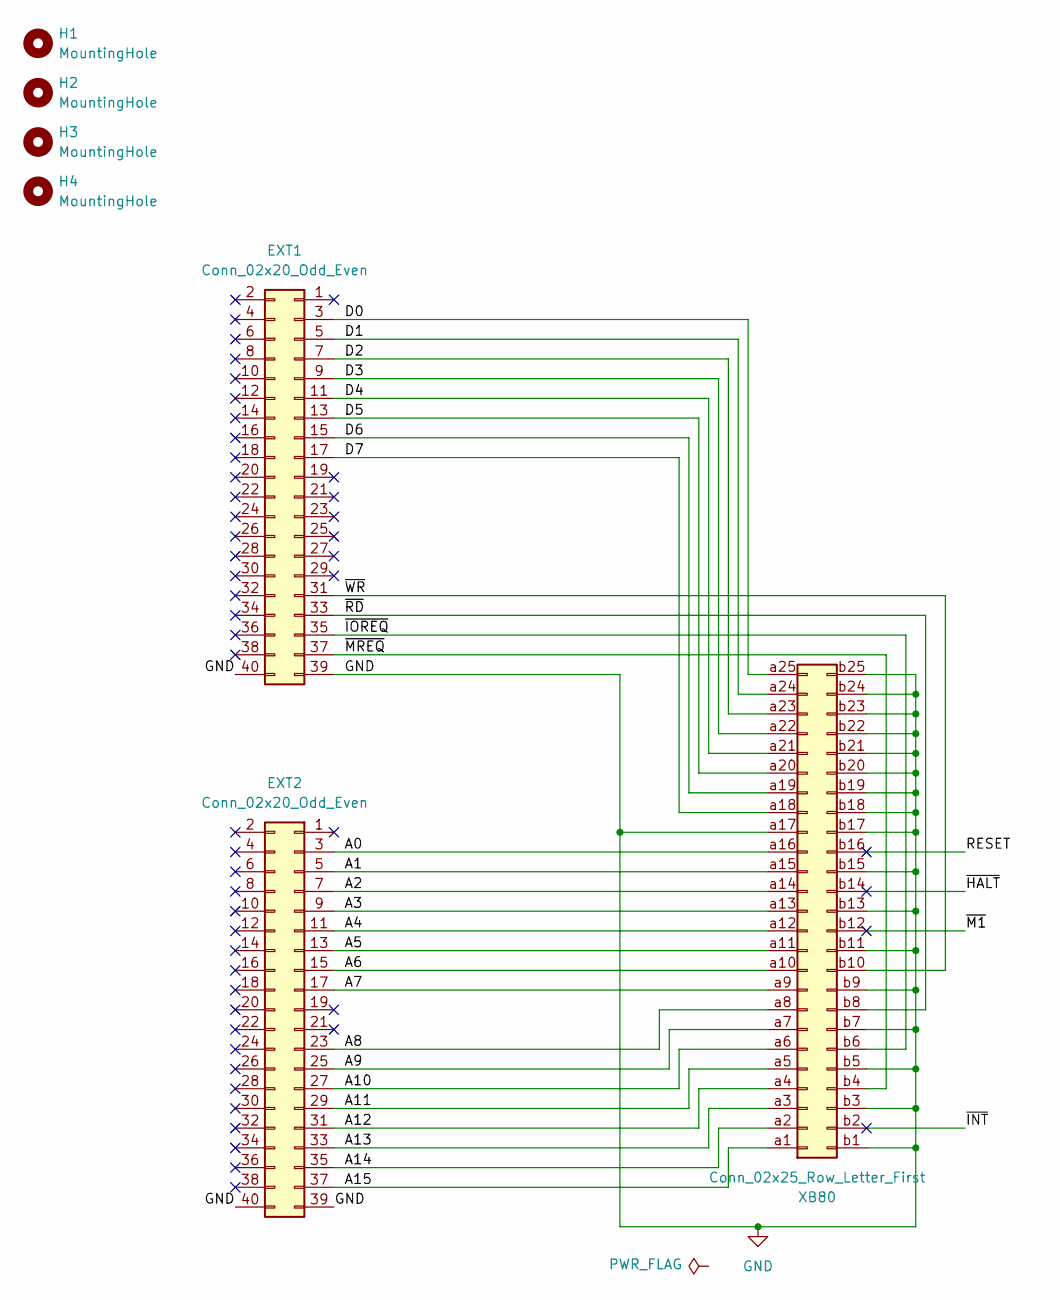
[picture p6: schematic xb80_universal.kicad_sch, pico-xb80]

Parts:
EXT1, EXT2: Conn_02x20_Odd_Even; PinSocket_2x20_P2.54mm_Vertical
H1, H2, H3, H4: MountingHole; MountingHole_2.7mm_M2.5
XB80: Conn_02x25_Row_Letter_First; IDC-Header_2x25_P2.54mm_Vertical

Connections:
/A0: EXT2.3, XB80.a16
/A1: EXT2.5, XB80.a15
/A2: EXT2.7, XB80.a14
/A3: EXT2.9, XB80.a13
/A4: EXT2.11, XB80.a12
/A5: EXT2.13, XB80.a11
/A6: EXT2.15, XB80.a10
/A7: EXT2.17, XB80.a9
/A8: EXT2.23, XB80.a8
/A9: EXT2.25, XB80.a7
/A10: EXT2.27, XB80.a6
/A11: EXT2.29, XB80.a5
/A12: EXT2.31, XB80.a4
/A13: EXT2.33, XB80.a3
/A14: EXT2.35, XB80.a2
/A15: EXT2.37, XB80.a1
/D0: EXT1.3, XB80.a25
/D1: EXT1.5, XB80.a24
/D2: EXT1.7, XB80.a23
/D3: EXT1.9, XB80.a22
/D4: EXT1.11, XB80.a21
/D5: EXT1.13, XB80.a20
/D6: EXT1.15, XB80.a19
/D7: EXT1.17, XB80.a18
/RESET: XB80.b16
/~HALT: XB80.b14
/~INT: XB80.b2
/~IOREQ: EXT1.35, XB80.b6
/~M1: XB80.b12
/~MREQ: EXT1.37, XB80.b4
/~RD: EXT1.33, XB80.b8
/~WR: EXT1.31, XB80.b10
GND: EXT1.39, EXT1.40, EXT2.39, EXT2.40, XB80.a17, XB80.b1, XB80.b3, XB80.b5, XB80.b7, XB80.b9, XB80.b11, XB80.b13, XB80.b15, XB80.b17, XB80.b18, XB80.b19, XB80.b20, XB80.b21, XB80.b22, XB80.b23, XB80.b24, XB80.b25

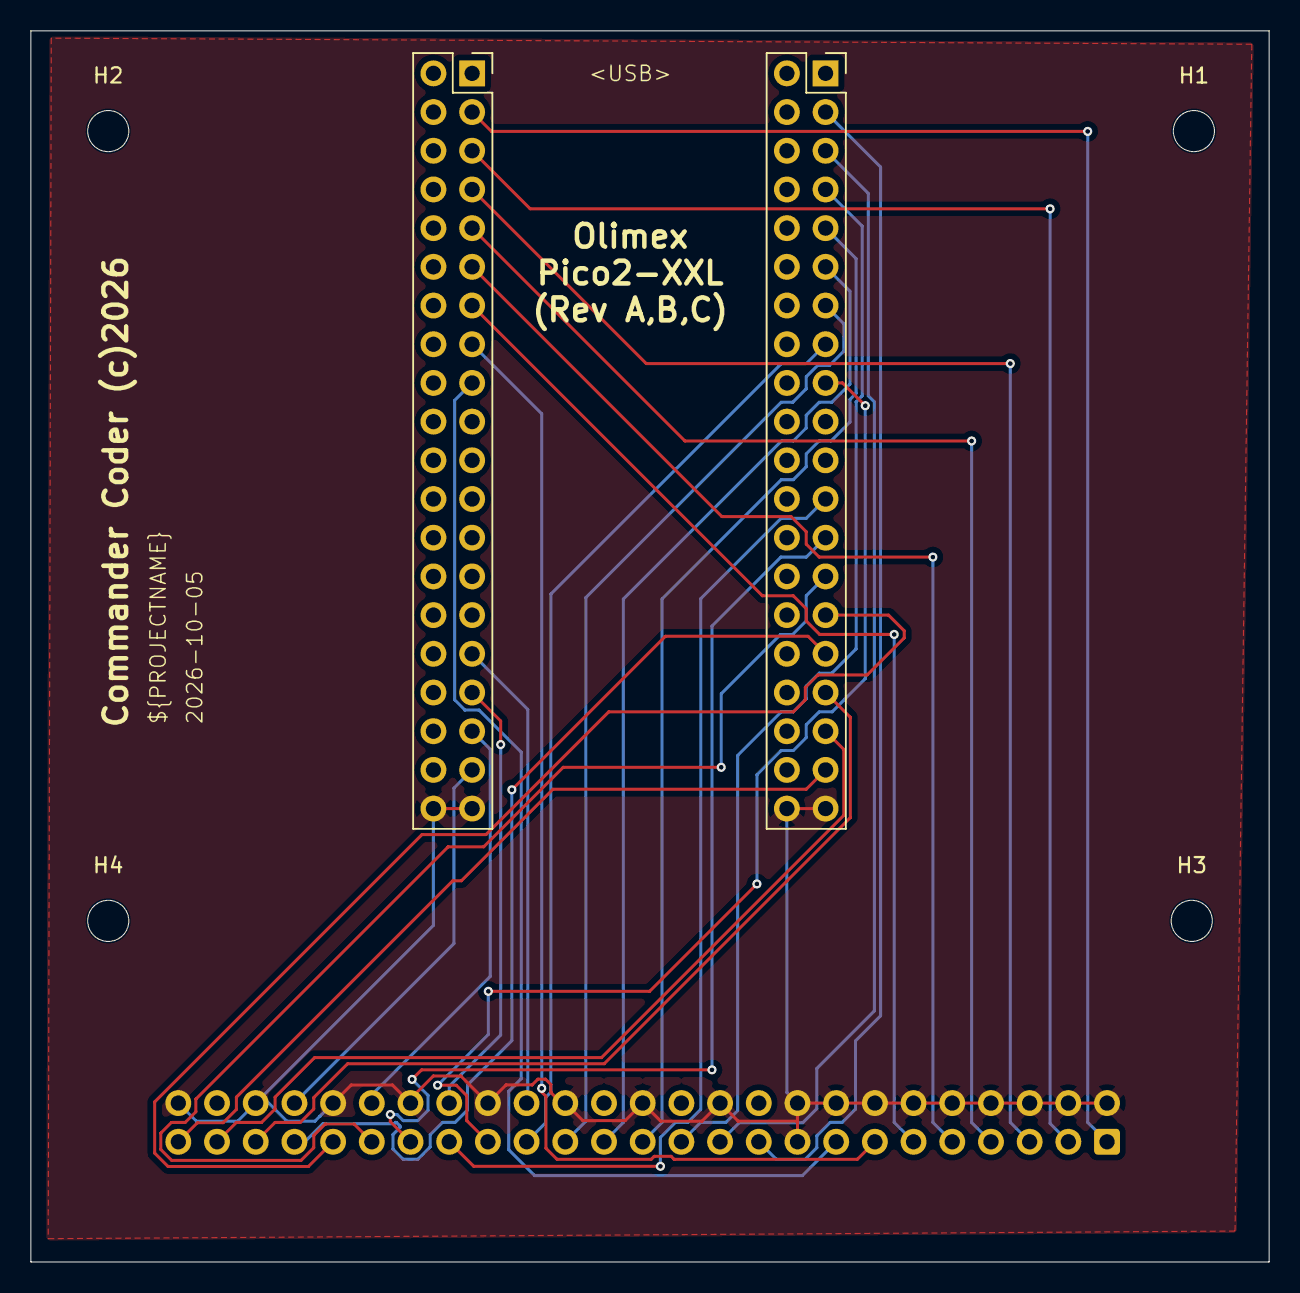
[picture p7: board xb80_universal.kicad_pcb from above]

Board: 2 copper layers, 81.3 x 80.8 mm, 7 parts (1 on the bottom side), 29 nets.

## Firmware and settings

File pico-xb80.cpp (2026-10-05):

// Copyright (c) Andrew Hague (Commander Coder), 21 September 2026
//
// This code may not be reused, in whole or in part, without attribution
// to the author, Andrew Hague (Commander Coder).

#include <stdio.h>
#include <stdint.h>
#include <strings.h> 

#include "pico/stdlib.h"

#include "fatfs_interface.h"

#include "xb_interface/xb_if.h"

#include "sharp-mz80k/sharp_mz.h"

#include "pico-xb80.h"



// Diagnostic: list every .MZF file on the SD card directly on the Pico side
// (no Z80/PIO involvement at all). Called from sdinit() after each successful
// mount as a sanity check of the SD/FatFs listing logic, independent of the
// Z80 transport.
void list_files_local(const char* extension, const char* rootdir)
{
  DIR dir;
  FILINFO fno;
  FRESULT result = f_opendir(&dir, rootdir);
  if (result != FR_OK) {
    _DEBUG("list_files_local: f_opendir failed");
    return;
  }

  _DEBUG("--- files on SD (Pico-local listing) ---\n");
  int count = 0;
  while (1) {
    result = f_readdir(&dir, &fno);
    if (result != FR_OK || fno.fname[0] == '\0') {
      break;
    }

    // Skip hidden files and directories
    int len = strlen(fno.fname);
    if (len == 0 || fno.fname[0] == '.' ) {
      continue;
    }

    // extension check: skip files that don't match the requested extension
    if (extension != nullptr && extension[0] != '\0') {
      int ext_len = strlen(extension);
      if (len < ext_len + 1 || fno.fname[len - ext_len - 1] != '.' || strncasecmp(fno.fname + len - ext_len, extension, ext_len) != 0) {
        continue;
      }
    }

    _DEBUG("  %s  (%lu bytes)\n", fno.fname, (unsigned long)fno.fsize);
    count++;
  }
  f_closedir(&dir);
  _DEBUG("---  %d file(s) found with extension .%s ---\n", count, extension);
}


// build a local cache of the files in the root directory which end in .MZF or .mzf
struct FileEntry {
  FILINFO fno;        // FATFS file info structure - the SD card filename
  char rawname[IBF_NAME_MAX + 1];     // IBF name exactly as the header holds it
  char displayname[IBF_NAME_MAX + 1]; // same, tagged <1 <2 ... if it is shared
  uint8_t attr;       // MZF type byte (header offset 0)
};

// 255 not 256 because FileCount is a count, and not an index, so the maximum index is 254, which is 255 entries in total.
static struct FileEntry FileList[255];
static uint8_t FileCount = 0; // number of files found

uint8_t getFileCount(void){
  return FileCount;
}

char* getDisplayName(uint8_t index){
  if (index >= FileCount) {
    return nullptr; // or handle error as appropriate
  }
  return FileList[index].displayname;
}

char* getFileName(uint8_t index){
  if (index >= FileCount) {
    return nullptr; // or handle error as appropriate
  }
  return FileList[index].fno.fname;
}

char* getRawName(uint8_t index){
  if (index >= FileCount) {
    return nullptr;
  }
  return FileList[index].rawname;
}

uint8_t getFileAttr(uint8_t index){
  if (index >= FileCount) {
    return 0;
  }
  return FileList[index].attr;
}

// Read the MZF header prefix: byte 0 is the file type and bytes 1..17 hold the
// IBF name terminated by CR. See OPERATING.md - the IBF name, not the SD card
// filename, is what gets listed and what filenames are compared against.
// Returns false if the file is too short or unreadable to carry a header.
static bool readHeaderInfo(const char* path, uint8_t* attr, char* ibf, size_t ibf_len)
{
  FIL fp;
  if (f_open(&fp, path, FA_READ) != FR_OK) {
    return false;
  }

  uint8_t hdr[IBF_NAME_OFFSET + IBF_NAME_MAX];
  UINT br = 0;
  FRESULT res = f_read(&fp, hdr, sizeof(hdr), &br);
  f_close(&fp);

  if (res != FR_OK || br < sizeof(hdr)) {
    return false;
  }

  *attr = hdr[0];

  // Header names are a fixed-width field, so they are commonly padded with
  // spaces at both ends. Trim them: the padding is not part of the name and
  // a leading space would otherwise defeat the menu's first-letter filter.
  size_t start = IBF_NAME_OFFSET;
  size_t end = IBF_NAME_OFFSET + IBF_NAME_MAX;
  for (size_t i = IBF_NAME_OFFSET; i < end; i++) {
    if (hdr[i] == 0x0D) { end = i; break; }   // CR ends the name field
  }
  while (start < end && hdr[start] == ' ') start++;
  while (end > start && hdr[end - 1] == ' ') end--;

  size_t n = 0;
  for (size_t i = start; i < end && n + 1 < ibf_len; i++) {
    unsigned char c = hdr[i];
    ibf[n++] = (c >= 32 && c <= 126) ? (char)c : '.';
  }
  ibf[n] = '\0';

  return n > 0;
}

// Append "<n" to a name, overwriting its tail if there is no room to grow.
static void tagName(char* name, size_t name_size, unsigned seq)
{
  char suffix[8];
  int slen = snprintf(suffix, sizeof(suffix), "<%u", seq);
  if (slen <= 0 || (size_t)slen >= name_size) return;

  const size_t room = name_size - 1;      // characters the buffer can hold
  size_t len = strlen(name);
  size_t at = (len + (size_t)slen <= room) ? len : room - (size_t)slen;

  memcpy(name + at, suffix, (size_t)slen);
  name[at + (size_t)slen] = '\0';
}

// IBF names are not unique - a patched copy normally keeps the header of the
// original it was built from, so two files happily claim the same name. Tag
// every member of such a group <1, <2, <3 ... so each can be picked out of the
// listing and referenced on its own.
//
// Only this scanned listing is tagged. The files on the card are not touched,
// and rawname still holds what the header actually says.
static void disambiguateNames(void)
{
  bool tagged[255] = { false };

  for (uint8_t i = 0; i < FileCount; i++)
  {
    if (tagged[i]) continue;

    // Count the files sharing this name, including this one
    uint8_t shared = 0;
    for (uint8_t j = i; j < FileCount; j++)
    {
      if (!tagged[j] && strcasecmp(FileList[j].rawname, FileList[i].rawname) == 0) shared++;
    }
    if (shared < 2) continue;

    // Number them in the order the directory scan found them
    const char* base = FileList[i].rawname;
    unsigned seq = 0;
    for (uint8_t j = i; j < FileCount; j++)
    {
      if (tagged[j] || strcasecmp(FileList[j].rawname, base) != 0) continue;
      tagName(FileList[j].displayname, sizeof(FileList[j].displayname), ++seq);
      tagged[j] = true;
    }
  }
}

void establishFileList(const char* rootdir)
{
  // Open root directory
  DIR dir;
  FILINFO fno;
  FRESULT result = f_opendir(&dir, rootdir);

  FileCount = 0; // reset file count
  
  // Count files in the root MZ_FD directory
  while (true)
  {
    result = f_readdir(&dir, &fno);
    if (result != FR_OK || fno.fname[0] == '\0')
    {
      // End of directory
      break;
    }

    int len = strlen(fno.fname);

    // Check for a .MZF/.mzf extension (case-sensitive match on both variants)
    if (len >= 4 && (!strcmp(fno.fname + len - 4, ".MZF") || !strcmp(fno.fname + len - 4, ".mzf")) && fno.fname[0] != '.')
    {
        struct FileEntry* entry = &FileList[FileCount];
        entry->fno = fno;
        entry->attr = 0;
        entry->rawname[0] = '\0';

        // The name to list is the IBF name inside the header, not the SD
        // card filename, so read it back out of the file itself.
        char path[300];
        snprintf(path, sizeof(path), "%s/%s", rootdir, fno.fname);

        if (!readHeaderInfo(path, &entry->attr,
                            entry->rawname, sizeof(entry->rawname)))
        {
            // No usable header - fall back to the SD name minus ".mzf" so the
            // file is still reachable rather than being listed as blank.
            int n = len - 4;
            if (n > (int)sizeof(entry->rawname) - 1)
                n = sizeof(entry->rawname) - 1;
            memcpy(entry->rawname, fno.fname, n);
            entry->rawname[n] = '\0';

        }

        // Starts out identical - disambiguateNames() adds a tag below if this
        // name turns out to be shared with another file.
        memcpy(entry->displayname, entry->rawname, sizeof(entry->rawname));

        if (++FileCount >= 255) break; // stop once the list is full
    }
  }
  f_closedir(&dir);

  disambiguateNames();

  // NOTE - FileCount is clamped to 255, so if there are more than 255 files, only the first 255 will be stored in FileList.


  // dump the file list for debugging
  _DEBUG("FileCount: %d\n", FileCount);
  for (uint8_t i = 0; i < FileCount; i++)
  {
    char othername[IBF_NAME_MAX + 1];
    memcpy(othername, FileList[i].rawname, sizeof(othername));
    int n = strlen(othername);
    for (int i = 0; i < n; i++)
     if ((unsigned char)othername[i] < 32 ||
        (unsigned char)othername[i] > 126)
        othername[i] = '.';

    _DEBUG("File %d: %s\n", i, othername);
  }
}


void init_led()
{
    // Initialize the GPIO pin for the LED
    gpio_init(PICO_DEFAULT_LED_PIN);
    gpio_set_dir(PICO_DEFAULT_LED_PIN, GPIO_OUT);
}

void set_led(bool on)
{
    gpio_put(PICO_DEFAULT_LED_PIN, on ? 1 : 0);
}


int main(void) {
    // prep USB logging
    stdio_init_all();
    sleep_ms(2000);

    _DEBUG("Pico-XB80 for Sharp MZ80K v1.0.0\n");

   

    // Start the Z80 expansion bus interface (PIO + DMA shadow memory). The
    // SD card and FatFs are brought up later by sdinit() from the command loop.
    start_xb_interface();

    // Initialise the Sharp MZ series interface
    SharpMZ_initialise();
    
  // prep GPIO for LED - must come after setup of interface 
  // since that will change pin 25 state to input for the SD card interface

    init_led();

    set_led(true);
    sleep_ms(1000);
    set_led(false); // force off

    // Start the command loop for Sharp MZ series commands
    SharpMZ_cmdloop();
    
    // Never reaches here, unless there is problem in cmdloop.
    while (1) {
        sleep_ms(1000);
    }
}

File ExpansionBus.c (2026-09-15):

/* Heavily based on ATOM-DVI EB methods */

#include "ExpansionBus.h"
#include "pico/rand.h"

#include "FD_rom.h"

#include "hardware/sync.h"

// using 0xFF00 in shadow memory as a communication area - Z80 writes commands and data here, and we can read it and respond accordingly

#define Z80_TO_PICO_DATA     0xFFFA
#define Z80_TO_PICO_FLAG     0xFFFB

#define PICO_TO_Z80_DATA     0xFFFC
#define PICO_TO_Z80_FLAG     0xFFFD


// PORTO at 0xE000 is the decoder which
// drives The keyboard rows

// NOTE: the Original FD; MZ-80FD + MZ-80FIO needed to be plugged into the IO Interface Unit MZ-80I/O
// when it was installed type FD would read the program from ROM at 0xf000-0xf3ff 
// It would use the 4 port addresses 0xf8-0xfb to interface and grab the first 14 sectors from
// track 0 into ram address 0x9800 (i.e. machine needs > 36Kb) and then executed at that address. 
// (128 bytes per sector)

// Possibly do the same by loading boot.mzf into 0x9800 and running it when FD is used (only if boot.mzf exists)
// and use *FDS to skip booting.

volatile uint16_t _Alignas(EB_BUFFER_LENGTH * 2) _eb_memory[EB_BUFFER_LENGTH] __attribute__((section(".uninitialized_dma_buffer")));

// we need two pios because NWR and NRD are on different pins.  Have a pio running the address program and read program.  Another pio responds to writes and handles events
static PIO eb2_dataread_pio = pio0;
static PIO eb2_datawrite_pio = pio1;

static uint eb2_dataread_sm = -1;
static uint eb2_dataread_sm_offset;

static uint eb2_datawrite_sm=-1;
static uint eb2_datawrite_sm_offset;


#define DATA_COUNT 8
#define ADDRESS_COUNT 16

static void eb_gpio_init()
{
    // Initialize all GPIO pins for the expansion bus
    // Data pins: 16-23
    // Control pins: 28-31 (NWR, NRD, NMREQ, NIOREQ)
    // Address pins: 32-47
    
    // Initialize pins for address/data/control: 16-47
    for (int i = PIN_D0; i < PIN_A0 + ADDRESS_COUNT; i++) {
        pio_gpio_init(eb2_dataread_pio, i);
    }

    // pio_gpio_init(eb2_datawrite_pio, PICO_DEFAULT_LED_PIN);

    // Pull-ups for address lines
    for (int pin = PIN_A0; pin < PIN_A0 + ADDRESS_COUNT; pin++) {
        gpio_pull_up(pin);
    }

    // Pull-ups for control lines
    gpio_pull_up(PIN_NWR);
    gpio_pull_up(PIN_NRD);
    gpio_pull_up(PIN_NMREQ);
    gpio_pull_up(PIN_NIOREQ);

    // Pull-ups for data lines
    for (int i = PIN_D0; i < PIN_D0 + DATA_COUNT; i++) {
        gpio_pull_up(i);
    }

}

static void eb2_read_program_init()
{
    eb2_dataread_pio = pio0;
    PIO pio = eb2_dataread_pio;

    // NEEDED!!
    bool success = pio_set_gpio_base(pio, 16); // set the gpio base to 16 so we can use pins 16-47 for the address and data lines
    assert(success);

    // Add read program and claim an unused state machine
    eb2_dataread_sm_offset = pio_add_program(pio, &eb2_read_program);
    eb2_dataread_sm = pio_claim_unused_sm(pio, true);

    uint sm = eb2_dataread_sm;
    uint offset = eb2_dataread_sm_offset;

    // NOT NEEDED! - all set as input - outputs will be set later
    // pio_sm_set_consecutive_pindirs(pio, sm, PIN_D0, 32, false);


    pio_sm_config c = eb2_read_program_get_default_config(offset);
    sm_config_set_in_pins(&c, PIN_A0); // starting here
    sm_config_set_out_pins(&c, PIN_D0, DATA_COUNT);

    sm_config_set_in_shift(&c, false, false, 0);

    uint address = (uint)&_eb_memory >> 17;

     uint zadd = ((uint)&_eb_memory >> 1) & 0xffff;
        printf("read _eb_memory  = %08lx (%04lx)\n",
       _eb_memory,zadd);

    int status;
    status = pio_sm_init(pio, sm, offset, &c);
    hard_assert(status == PICO_OK);
    pio_sm_put(pio, sm, address);
    pio_sm_exec(pio, sm, pio_encode_pull(false, true) );
    pio_sm_exec(pio, sm, pio_encode_mov(pio_x, pio_osr));
    pio_sm_exec(pio, sm, pio_encode_nop() );

}


static void eb2_write_program_init()
{
    eb2_datawrite_pio = pio1;
    PIO pio = eb2_datawrite_pio;

    // NEEDED!!
    bool success = pio_set_gpio_base(pio, 16); // set the gpio base to 16 so we can use pins 16-47 for the address and data lines
    assert(success);

    // Add read program and claim an unused state machine
    eb2_datawrite_sm_offset = pio_add_program(pio, &eb2_write_program);
    assert(eb2_datawrite_sm_offset);
    eb2_datawrite_sm = pio_claim_unused_sm(pio, true);
    assert(eb2_datawrite_sm);

    uint sm = eb2_datawrite_sm;
    uint offset = eb2_datawrite_sm_offset;

    // Ensure data pins are configured as inputs for the write state machine
    // default for PIO is input
    // NOT NEEDD
    // pio_sm_set_consecutive_pindirs(pio, sm, PIN_D0, DATA_COUNT+8+ADDRESS_COUNT, false);
    
    //pio_sm_set_consecutive_pindirs(pio, sm, PICO_DEFAULT_LED_PIN, 1, true);

    pio_sm_config c = eb2_write_program_get_default_config(offset);
    sm_config_set_in_pins(&c, PIN_A0); // starting here (will wrap if ask for 32 bits)
    // no need to set out_pins as all data is coming in from Z80
    
    //sm_config_set_set_pins(&c, PICO_DEFAULT_LED_PIN, 1);

    sm_config_set_jmp_pin(&c, PIN_NWR);
    
    sm_config_set_in_shift(&c, false, false, 0);
    sm_config_set_out_shift(&c, true, false, 0); // out doesn't go to PINS, just used for data manipulation

    // float freq = 0.1f;
    // float div = (float)clock_get_hz(clk_sys) / (freq * 128.0f);
    // sm_config_set_clkdiv(&c, div);


    uint address = (uint)&_eb_memory >> 17;

     uint zadd = ((uint)&_eb_memory >> 1) & 0xffff;
        printf("write _eb_memory  = %08lx (%04lx)\n",
       _eb_memory,zadd);

    int status;
    status = pio_sm_init(pio, sm, offset, &c);
    hard_assert(status == PICO_OK);

    pio_sm_put(pio, sm, address);
    pio_sm_exec(pio, sm, pio_encode_pull(false, true) );
    pio_sm_exec(pio, sm, pio_encode_mov(pio_x, pio_osr));
    pio_sm_exec(pio, sm, pio_encode_nop() );

    // address base sent to write code so it can read/write to the correct area


}

    uint address_chan   ;
    uint read_data_chan ;
    uint write_data_chan;
    uint write_read_data_chan;
    uint save_addr_chan;
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

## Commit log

2026-09-16 another tidy up to extract sharpmz code from the xb_if and main pico-xb80
2026-09-17 added LED when accessing files
2026-09-19 Align ROM/Pico directory listing and file-type filtering Resolve files by IBF names for load, copy, and rename Correct MZF header offsets when saving files Update related operating documentation
    [pico-xb80.cpp]
2026-09-25 Add video link and thumbnail to README
    Added a video link and thumbnail for pico-xb80.
2026-10-04 switched IOREQ and MREQ pins (to follow same order as on the ribbon cable). Added a first version of hardware for the interface board
    [ver1.kicad_pcb, ver1.kicad_sch]
2026-10-04 adding output for HARDWARE
    [ver1-B_Cu.gbr, ver1-B_Mask.gbr, ver1-B_Paste.gbr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]
2026-10-05 Drive the SD card over hardware SPI when the wiring allows it
    SdCard::initialize() now picks a transport instead of always bit-banging.
    SPI moves a sector as 512 hardware-clocked bytes at 12.5MHz rather than
    4096 GPIO transitions paced by sleep_us(), and frees the core during the
    transfer. The native 1-bit path is unchanged and remains the fallback.
    Availability is a property of the wiring, not a choice: bank-0 FUNCSEL 1
    cycles RX/CSn/SCK/TX every four GPIOs and alternates spi0/spi1 every
    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
2026-10-05 Detect the board revision and pick the SD pin and transport from it
    The two Olimex RP2350-PICO2-XXL revisions wire the SD socket differently,
    so hardcoding either one was always going to be wrong on the other.
    Revision A has SD_DAT0 on GPIO12 and leaves R24 - the 33R link between
    GPIO9 and the card's CD/DAT3/CS pin - unpopulated, so CS cannot be
    asserted and SPI is not available at all. Revision B moved SD_DAT0 to
    GPIO24, GPIO12 having collided with the RP2350's HSTX/HDMI block, and
    ships wired for SPI.
    detect_board_revision() tells them apart electrically rather than by
    asking the card: it enables the RP2350's internal pull-down on each
    candidate pin and looks for the 10k pull-up that the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
    [sd_card.cpp]
2026-10-05 List every root file at SD init, and match extensions of any length
    list_files_local() treated an empty extension as "match nothing" and
    only ever compared the last three characters, so it could neither list
    a whole directory nor tell "foo.mzf" from "foomzf". It now skips the
    check when no extension is given, and otherwise requires a '.' right
    before an extension of whatever length was asked for.
    sdinit() uses that to dump the root directory before the .mzf listing,
    which makes a mount problem easier to tell apart from a missing
    ROOT_DIR. The header line also gains the newline it was missing.
    [pico-xb80.cpp]
2026-10-05 Space the EXT headers to fit Olimex Rev B and Rev C, and clean up ERC
    The Olimex RP2350-PICO2-XXL moved its EXT headers between revisions:
    pin 1 to pin 1 is 23.54mm on Rev A/B and 22.86mm on Rev C. The sockets
    were 23.50mm apart, which suits Rev B but leaves a Rev C 0.64mm out -
    enough to bend pins. EXT2 now sits at 23.20mm, splitting the difference
    so either revision is 0.34mm out. The sockets stay on F.Cu: the Olimex
    plugs in face-up from above with its headers on its underside, so both
    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
    [ver1-B_Cu.gbr, ver1-B_Mask.gbr, ver1-B_Paste.gbr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]
2026-10-05 Split the hardware into xb80_1 and xb80_universal projects
    The original board moves to HARDWARE/xb80_1 unchanged in substance.
    xb80_universal is the board to build: EXT headers 23.20mm apart so
    Olimex Rev A/B and Rev C all fit, GND on EXT1.40 and EXT2.39/40 as well
    as EXT1.39, a GND pour that reaches every ground pad, and the XB80 box
    header on the underside so the ribbon cable plugs in from below while
    the Olimex sits on top. Its Gerbers ship as output.zip, with the
    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
    [ver1-B_Cu.gbr, ver1-B_Mask.gbr, ver1-B_Paste.gbr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]

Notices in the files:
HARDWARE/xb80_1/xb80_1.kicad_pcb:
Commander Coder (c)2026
